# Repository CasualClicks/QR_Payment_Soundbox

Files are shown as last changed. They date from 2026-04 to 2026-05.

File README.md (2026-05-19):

<!-- Generated using AI to save time -->

# 🔊 QR Payment Soundbox

A DIY **QR Payment Soundbox** built using an ESP32 that announces payment confirmations in real-time — matching the performance of commercial UPI soundboxes, but engineered for both **personal (non-merchant) and scalable future use cases**.

---

## 🚀 Overview

This project enables real-time, dynamic **audio announcements for UPI payments** by:

- Subscribing to instant payment payloads via MQTT.
- Parsing numerical amounts and currency fragments asynchronously.
- Outputting clean audio pacing structures through a local hardware decoding matrix.

### Current Support Status:
- 🧑‍💻 **Non-Merchant Mode (Fully Working):** Mobile Phone (SMS Notification App) ➡️ MQTT Broker ➡️ ESP32 WiFi/GPRS Node.
- 🏪 **Merchant Standalone Mode (Hardware Ready / Code Pending):** Circuit architecture accommodates an onboard GSM module for future standalone decoding, currently awaiting firmware implementation.

---

## 📺 Project Demonstration

<div align="center">
  <a href="YOUR_YOUTUBE_VIDEO_URL_HERE">
    Watch the Soundbox Demo
    <br>
    <b>▶️ Click to watch the Soundbox boot up, handle cellular authentication, and process a live transaction payload test</b>
  </a>
</div>

---

## 🧩 Features

- 🔊 **Dynamic Audio Stitching:** Glitch-free compounding playback (e.g., *"Amount received: One Hundred and Fifty Rupees and Fifty Paise"*).
- 📶 **Network Tunnelling:** ESP32 establishes internet access over cellular GPRS (SIM800L) to pull cloud events without local WiFi infrastructure.
- 🎛️ **Compact Amplification Loop:** Minimalist, knobless audio pipeline maximizing space-efficiency.
- 🧠 **Non-Blocking Queue:** Dedicated software state machine managing precise multi-track spacing using dummy timer folders.
- 🧱 **Industrial Form Factor:** Custom-fitted, high-stability 3D printed enclosure.

---

## 🛠️ Hardware Components

| Component | Functional Purpose |
|---|---|
| **ESP32 Core Module** | Central processing unit handling network state machines and audio flow control. |
| **DFPlayer Mini** | Hardware MP3/WAV storage subsystem and local DAC decoder. |
| **PAM8403 Module** | Knobless Mini Class-D Audio Power Amplifier delivering maximum power density. |
| **3W 4Ω Speaker** | Acoustically matched low-impedance audio driver. |
| **SIM800L Core** | GSM/GPRS module providing cellular data connectivity to the MQTT server. |
| **MT3608 DC-DC Boost** | High-transient voltage rail stabilization (Step-up to distinct 4V/5V system domains). |
| **18650 Battery Array** | Core high-discharge portable power cell layout. |
| **Decoupling Capacitors** | Focused $1000\mu F$ low-ESR buffer sitting directly across the cellular power rail. |

---

## 🧠 System Architecture

### 🔹 Non-Merchant Mode (Active Infrastructure)
Payment SMS → Mobile Phone → MQTT Server → ESP32 → Audio Output
1. Payment landing triggers a transactional SMS on a personal smartphone.
2. A background application on the phone reads the broadcast notification and posts a raw string token to the Adafruit IO MQTT broker.
3. The standalone soundbox connects via SIM800L GPRS, extracts the payload value, sanitizes the float bounds, and initiates the local speech thread.

### 🔹 Standalone Merchant Mode (Future Capability)
- SIM800 receives SMS directly  
- ESP32 processes message  
- Fully independent system  
- **Current State:** The wiring matrix accommodates hardware mapping to capture cellular broadcasts natively, but firmware parsing logic is currently placeholder code slated for a future update.
---

## 🔌 Wiring Overview
### 🎛️ Microcontroller Routing Matrix
```cpp
// Hardware Serial 1 Allocation (Cellular Core)
#define ESP_RX_SIM_TX 4  // Connect to SIM800L TX
#define ESP_TX_SIM_RX 5  // Connect to SIM800L RX (Use 1k resistor inline)

// Hardware Serial 2 Allocation (Audio Core)
#define ESP_RX_DF_TX  27 // Connect to DFPlayer Mini TX
#define ESP_TX_DF_RX  25 // Connect to ESP32 TX ---> DFPlayer RX (Use 1k resistor inline)
```
---

## 🔊 Knobless Audio Execution Path
To maximize space and reduce manual physical tuning inside the housing, a knobless PAM8403 module is deployed. Volume adjustments are configured 100% via firmware down to the DFPlayer DAC line (df.volume(15) to 25).

DFPlayer DAC_R / DAC_L -> Routed directly to the PAM8403 Left / Right Input terminals.

DFPlayer GND ➡️ Tied directly to PAM8403 Audio Input Ground.

PAM8403 Output (L+/L- or R+/R-) ➡️ Wired directly to the 3W 4Ω Speaker.

---

## 🔊 Audio Strategy

- Uses **pre-recorded audio clips**
  
SD CARD ROOT/
├── 01/             # Core Numeric Elements [F_NUM]
│   ├── 001.wav     # "One"
│   ├── 020.wav     # "Twenty"
│   └── 030.wav     # "Hundred / Thousand" markers
├── 02/             # Device Status Alerts [F_SYS]
│   ├── 001.wav     # System Booting Sound (S_BOOTING)
│   ├── 002.wav     # Network Registered Sound (S_NETWORK)
│   ├── 003.wav     # Incoming Message Alert Ding (S_DING)
│   └── 004.wav     # Device Online & MQTT Ready (S_READY)
├── 03/             # Sentence Joining Fragments [F_WORDS]
│   ├── 001.wav     # "Paise" (W_PAISE)
│   ├── 002.wav     # "Rupees" (W_RUPEES)
│   ├── 003.wav     # "And" (W_AND)
│   ├── 004.wav     # "Amount" (W_AMOUNT)
│   └── 005.wav     # "Received" (W_RECEIVED)
└── 04/             # Exception Warnings [F_ERR]
    ├── 001.wav     # No Cellular Service Alert (E_NO_SRV)
    ├── 002.wav     # Failed Payment Status (E_NO_PAY)
    └── 003.wav     # General System Hardware Error (E_ERROR)
    
Supports:
- Dynamic composition (number + words)
- OR pre-generated full phrases (recommended)

👉 Recommended format:
- WAV (16-bit, 16kHz, mono)

---

## 🧪 Prototyping & Testing

Before full enclosure integration, individual modules were rigorously unit-tested across power draw cycles.

### 🔬 Evolution Stages
<div align="center">
  Breadboard Circuit Layout
  Assembled Hardware Matrix
  <p><i>Left: Prototype breadboard validation circuit. Right: Main components integrated with power rails inside the final housing chassis.</i></p>
</div>

### ✅ Unit Tests Conducted
- ESP32 ↔ DFPlayer serial command continuity  
- SIM800L registration stabilization under $2\text{A}$ transient load bursts  
- Cellular GPRS session persistence & MQTT heartbeat logic (`state == -1` mitigation)  

---

### ✅ Unit Tests Conducted
- ESP32 ↔ DFPlayer communication  
- ESP32 ↔ SIM800 communication  
- Audio playback stability  
- Power supply reliability  
- MQTT message handling  

### 🔬 Prototype Iterations
- Breadboard setup  
- Perfboard integration  
- Full system assembly  

📸 Images of each stage are included in the repository.

---

## 🧱 Enclosure Design & CAD

- Custom designed multi-piece shell engineered within Fusion 360 to optimize acoustic resonance and component packaging constraints.

<div align="center">
  Fusion 360 Model
  3D Printed Components
  <br>
  Mechanical Assembly Fit Test
  <p><i>Top-Left: 3D modeling and layout parameters. Top-Right: Raw printed shells. Bottom: Structural test alignment before final adhesive lock.</i></p>
</div>

Designed to:
- Securely mount the 18650 cell cluster and MT3608 buck-boost converter safely.
- Feature internal guide tracks for optimal cellular antenna separation from audio traces.
- Support interchangeable front branding faceplates.

---

## ⚡ Power Design

- Battery-powered system  

Using DC-DC boosters for:
- Stable 5V (ESP32, DFPlayer, PAM)
- Stable ~4V (SIM800)

👉 Decoupling capacitors added for stability

---

## 🌐 MQTT Integration

- **Broker Target Host:** `io.adafruit.com` (Port: `1883`)
- **Subscription Feed:** `CasualClicks/feeds/amount`
- **Handshake Tuning:** Buffer depth is explicitly extended to `512` bytes with a robust `120s` keep-alive threshold to smoothly navigate high-latency cellular network environments.

### Expected Metric Payload Object:
```json
{
  "amount": "250.75"
}
```
---

## 📈 Scalability

- Supports multiple devices via MQTT  
- Can be deployed across shops  
- SIM-based version removes dependency on phone  

---

## 🔮 Future Improvements

- App-based dashboard  
- Multi-language support  
- Voice customization  
- Better audio stitching  
- OTA updates  
- Battery optimization  

---

## 🌍 Project Showcase

This project will also be showcased on:  
👉 https://www.officialshivam.in/

---

## 🤝 Contributions

Feel free to:

- Open issues  
- Suggest improvements  
- Fork and build your own version  

---

## 📜 License

MIT License

---

## 🙌 Acknowledgements

Inspired by real-world UPI soundboxes used in retail environments.

---

## 📬 Contact

**Shivam Singhal**

For queries, collaborations, or improvements — feel free to reach out!

---

⭐ If you found this useful, consider starring the repo!

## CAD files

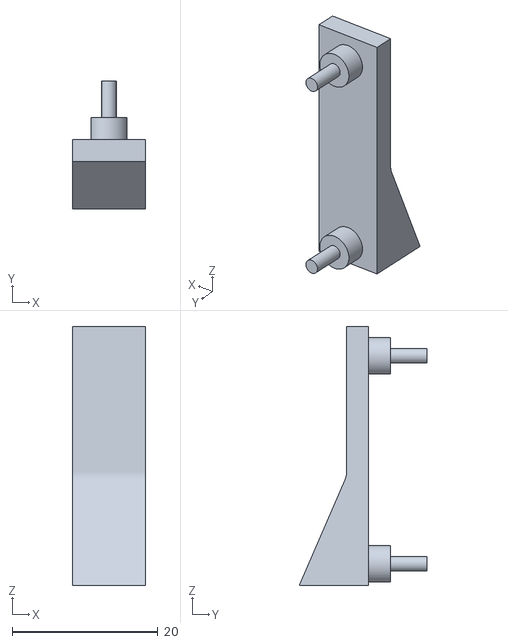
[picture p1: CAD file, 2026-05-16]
Bracket_2_V1.stl
10.0 x 17.5 x 35.5

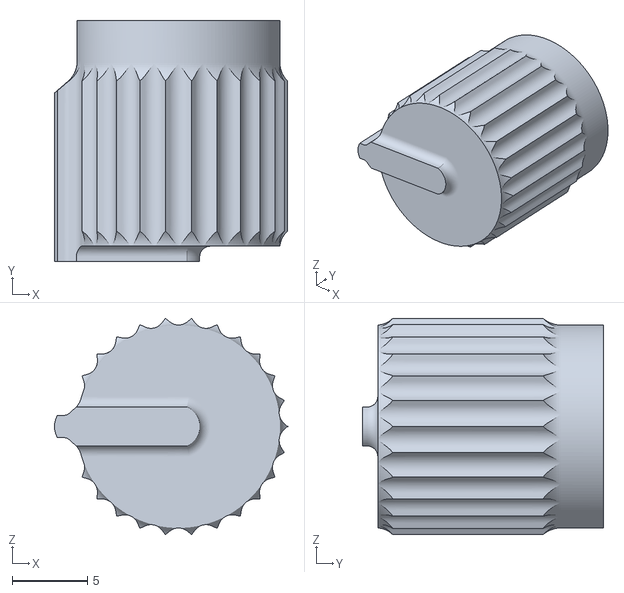
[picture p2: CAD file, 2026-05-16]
VolumeKnobV4.stl
15.5 x 16.0 x 14.4

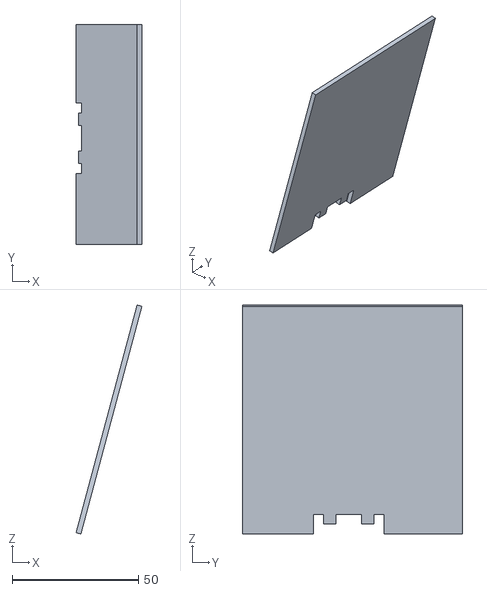
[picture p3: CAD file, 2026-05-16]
Soundbox_QR_Plate_V2.stl
26.1 x 87.0 x 90.7

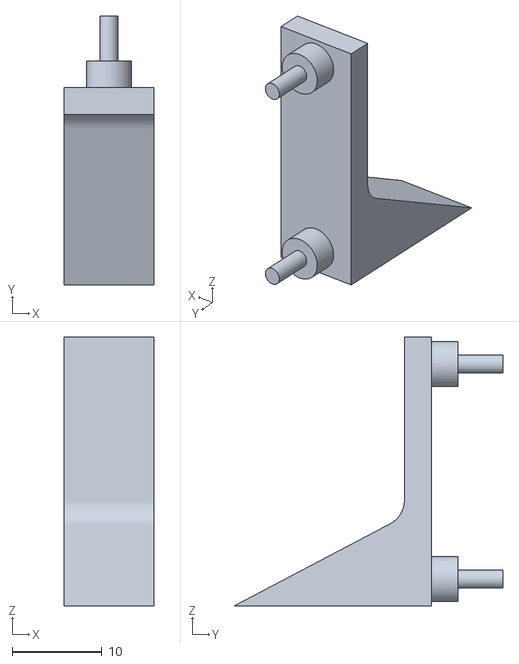
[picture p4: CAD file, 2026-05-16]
Bracket_1_V1.stl
10.0 x 30.0 x 30.0

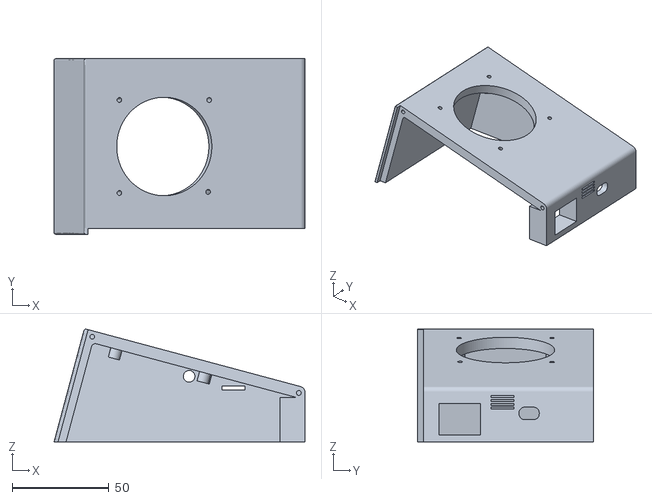
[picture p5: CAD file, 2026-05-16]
soundbox_shell_V1.stl
130.0 x 91.0 x 58.5

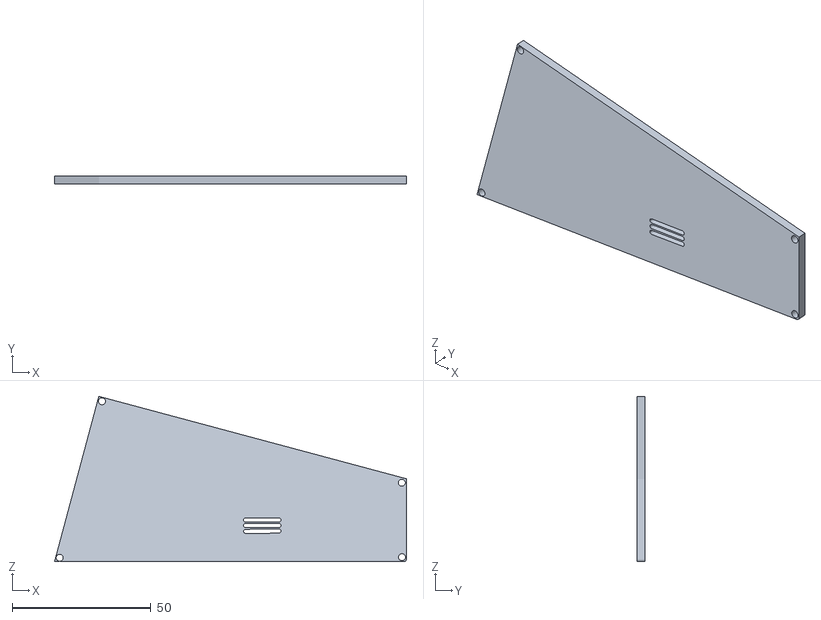
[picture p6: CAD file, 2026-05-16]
Soundbox_Screw_Plate_V1.stl
126.7 x 3.00 x 59.5

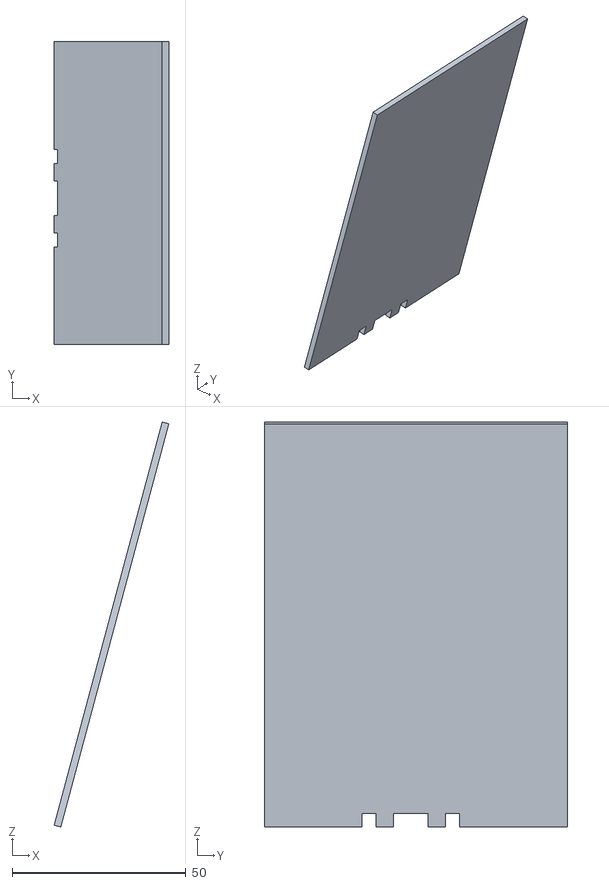
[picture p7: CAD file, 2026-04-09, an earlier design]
Soundbox_QR_Plate_V1.stl
33.0 x 87.0 x 116.4

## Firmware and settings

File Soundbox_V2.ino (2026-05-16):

#include <Arduino.h>
#define TINY_GSM_MODEM_SIM800
#include <TinyGsmClient.h>
#include <PubSubClient.h>
#include <HardwareSerial.h>
#include <DFRobotDFPlayerMini.h>

// ================= CONFIG =================
const char apn[]      = "www";   // VI APN
const char gprsUser[] = "";
const char gprsPass[] = "";

const char* broker    = "io.adafruit.com";
const char* topic     = "OUR_ADAFRUIT_TOPIC";
const char* mqtt_user = "YOUR_ADAFRUIT_USER";
const char* mqtt_pass = "YOUR_ADAFRUIT_KEY";

bool isFirstConnect = true; 
// ================= PINS =================
#define ESP_RX_SIM_TX 4 
#define ESP_TX_SIM_RX 5 
#define ESP_RX_DF_TX  27
#define ESP_TX_DF_RX  25

// ================= AUDIO MAP =================
// Folders
#define F_NUM    1
#define F_SYS    2
#define F_WORDS  3
#define F_ERR    4
#define F_PAUSE  99 // MAGIC FOLDER: Used to create silent gaps

// System Sounds (Folder 02)
#define S_BOOTING  1
#define S_NETWORK  2
#define S_DING     3
#define S_READY    4

// Word Sounds (Folder 03)
#define W_PAISE    1
#define W_RUPEES   2
#define W_AND      3
#define W_AMOUNT   4
#define W_RECEIVED 5

// Error Sounds (Folder 04)
#define E_NO_SRV   1
#define E_NO_PAY   2
#define E_ERROR    3

// ================= OBJECTS =================
HardwareSerial SerialAT(1);
HardwareSerial mp3Serial(2);
TinyGsm modem(SerialAT);
TinyGsmClient client(modem);
PubSubClient mqtt(client);
DFRobotDFPlayerMini df;

// ================= AUDIO QUEUE =================
int queue[40]; 
int queueSize = 0, currentIndex = 0;

bool isPlaying = false;
unsigned long lastCommandTime = 0;

// Pause Variables
bool isPausing = false;
unsigned long pauseEndTime = 0;

void addToQueue(int folder, int file) {
  if (queueSize < 40) queue[queueSize++] = (folder * 10000) + file;
}

void playNext() {
  if (currentIndex >= queueSize) {
    isPlaying = false;
    isPausing = false;
    queueSize = 0;
    currentIndex = 0;
    Serial.println("[INFO] Audio queue finished");
    return;
  }

  int val = queue[currentIndex++];
  int folder = val / 10000;
  int file = val % 10000;

  if (folder == F_PAUSE) {
    Serial.printf("[INFO] Silent Pause for %d ms...\n", file);
    pauseEndTime = millis() + file;
    isPausing = true;
    isPlaying = false;
  } 
  else {
    Serial.printf("[INFO] Playing -> Folder: %02d | File: %03d\n", folder, file);
    df.playFolder(folder, file);
    lastCommandTime = millis();
    isPlaying = true;
    isPausing = false;
  }
}

void queueNumber(long num) {
  if (num == 0) return;

  if (num <= 20) {
    addToQueue(F_NUM, num);
  } 
  else if (num < 100) {
    addToQueue(F_NUM, (num / 10) + 18); 
    if (num % 10) queueNumber(num % 10);
  } 
  else if (num < 1000) {
    queueNumber(num / 100);
    addToQueue(F_NUM, 28); 
    if (num % 100) queueNumber(num % 100);
  }
  else if (num < 100000) {
    queueNumber(num / 1000);
    addToQueue(F_NUM, 29); 
    if (num % 1000) queueNumber(num % 1000);
  }
  else {
    queueNumber(num / 100000);
    addToQueue(F_NUM, 30); 
    if (num % 100000) queueNumber(num % 100000);
  }
}

// ==== UPGRADED PARSER FOR PAISE ====
void speakAmount(String amount) {
  amount.trim();
  if (amount.length() == 0) return;

  long rupeesVal = 0;
  long paiseVal = 0;

  // Check if there is a decimal point
  int dotIndex = amount.indexOf('.');
  
  if (dotIndex != -1) {
    // Extract the Rupees part before the dot
    rupeesVal = amount.substring(0, dotIndex).toInt();
    
    // Extract the Paise part after the dot
    String pStr = amount.substring(dotIndex + 1);
    
    // Safety check: if they send "150.5" it means 50 paise.
    if (pStr.length() == 1) {
      pStr += "0"; 
    } else if (pStr.length() > 2) {
      pStr = pStr.substring(0, 2); // Ignore anything past 2 decimals
    }
    paiseVal = pStr.toInt();
  } else {
    // No decimal found, it's just pure rupees
    rupeesVal = amount.toInt();
  }

  // If amount is literally 0.00, ignore it
  if (rupeesVal <= 0 && paiseVal <= 0) return;

  Serial.println("\n[EVENT] Processing Payment: ₹" + amount);
  Serial.printf("[INFO] Parsed -> Rupees: %ld | Paise: %ld\n", rupeesVal, paiseVal);

  queueSize = 0;
  currentIndex = 0;

  // ==== THE PACING SEQUENCE ====
  addToQueue(F_SYS, S_DING);       // 1. Play the Ding
  addToQueue(F_PAUSE, 500);        // 2. Pause
  
  addToQueue(F_WORDS, W_AMOUNT);   // 3. "Amount"
  addToQueue(F_WORDS, W_RECEIVED); // 4. "Received"
  
  // 5. Speak Rupees (if any)
  if (rupeesVal > 0) {
    queueNumber(rupeesVal);        
    addToQueue(F_WORDS, W_RUPEES); // "Rupees"
  }

  // 6. Speak Paise (if any)
  if (paiseVal > 0) {
    // If we already said rupees, insert the word "And"
    if (rupeesVal > 0) {
      addToQueue(F_WORDS, W_AND);  
    }
    queueNumber(paiseVal);         // Speak the decimal numbers
    addToQueue(F_WORDS, W_PAISE);  // "Paise"
  }

  playNext(); // Kick off the queue
}

// ================= MQTT =================
void callback(char* topic, byte* payload, unsigned int len) {
  char msg[len + 1];
  memcpy(msg, payload, len);
  msg[len] = '\0';

  Serial.println("[INFO] MQTT Message Received: " + String(msg));
  speakAmount(String(msg));
}

void connectMQTT() {
  String clientId = "SoundBox-" + String(micros());

  // Add a local counter to prevent the "No Service" sound from looping
  int retryCount = 0;

  while (!mqtt.connected()) {
    modem.sendAT("+CNETLIGHT=1"); 
    modem.waitResponse();

    Serial.println("[INFO] Connecting to MQTT Broker...");

    if (mqtt.connect(clientId.c_str(), mqtt_user, mqtt_pass)) {
      Serial.println("[INFO] MQTT Connected Successfully!");
      mqtt.subscribe(topic);
      
      modem.sendAT("+CNETLIGHT=0"); 
      modem.waitResponse();
      
      // Only play "Ready" on the very first successful boot
      if (isFirstConnect) {
        df.playFolder(F_SYS, S_READY); 
        isFirstConnect = false; 
      }
      else{
      Serial.println("[INFO] MQTT Reconnected");      
      }
    } 
    else {
      Serial.print("[WARN] MQTT Failed, rc=");
      Serial.println(mqtt.state());
      
      // ONLY play "No Service" on the first failure. 
      // This prevents the box from shouting every 5 seconds.
      if (retryCount == 0 && isFirstConnect) {
         df.playFolder(F_ERR, E_NO_SRV); 
      }
      
      retryCount++;
      delay(5000); // Wait 5 seconds before trying again
    }
  }
}

// ================= SETUP =================
void setup() {
  Serial.begin(115200);
  delay(3000);

  Serial.println("\n=================================");
  Serial.println("    SOUNDBOX BOOT SEQUENCE       ");
  Serial.println("=================================");
  randomSeed(micros());

  // --- DFPlayer Init ---
  Serial.println("[INIT] Starting DFPlayer...");
  mp3Serial.begin(9600, SERIAL_8N1, ESP_RX_DF_TX, ESP_TX_DF_RX);
  if (!df.begin(mp3Serial)) {
    Serial.println("[ERROR] DFPlayer missing or wiring faulty!");
  } else {
    Serial.println("[INFO] DFPlayer Ready. Volume set to 25.");
    df.volume(15);
    df.playFolder(F_SYS, S_BOOTING); 
  }

  // --- SIM800 Init ---
  Serial.println("[INIT] Starting SIM800L...");
  SerialAT.begin(9600, SERIAL_8N1, ESP_RX_SIM_TX, ESP_TX_SIM_RX);

  // FORCE NETLIGHT ON IMMEDIATELY
  // We send a raw AT command because 'modem.init()' hasn't passed yet
  Serial.println("[DEBUG] Forcing Netlight ON for troubleshooting...");
  SerialAT.println("AT+CNETLIGHT=0"); 
  delay(100);
  
  Serial.println("[INFO] Syncing Modem...");
  if (!modem.init()) {
    Serial.println("[ERROR] Modem init failed! Check power/wiring.");
    df.playFolder(F_ERR, E_ERROR); 
    while (true);
  }
  
  modem.sendAT("+CNETLIGHT=0"); 
  modem.waitResponse(); 
  Serial.println("[INFO] Netlight disabled.");
  
  Serial.println("[INFO] Waiting for cellular network...");
  if (!modem.waitForNetwork(60000L)) {
    Serial.println("[ERROR] No Network Signal.");
    df.playFolder(F_ERR, E_ERROR);
    while (true); 
  }

  Serial.println("[INFO] Cellular Network Found!");

  Serial.println("[INFO] Establishing GPRS (Internet)...");
  if (!modem.gprsConnect(apn, gprsUser, gprsPass)) {
    Serial.println("[ERROR] GPRS Connection Failed.");
    df.playFolder(F_ERR, E_NO_SRV);
    while (true); 
  }

  Serial.println("[INFO] Internet Connection Established!");
  df.playFolder(F_SYS, S_NETWORK); 

  mqtt.setServer(broker, 1883);
  mqtt.setCallback(callback);

  mqtt.setBufferSize(512);   // Gives more room for cellular data packets
  mqtt.setKeepAlive(120);    // Tells Adafruit to wait 2 minutes before disconnecting


  Serial.println("[INFO] Setup Complete. Entering Loop.");
}

// ================= LOOP =================
void loop() {
  if (!mqtt.connected()) {
    Serial.print("[DEBUG] Connection lost. Internal State: ");
    Serial.println(mqtt.state()); // This will tell us WHY it dropped
    connectMQTT();
  }

  mqtt.loop();

  if (isPausing && (millis() >= pauseEndTime)) {
    playNext();
  }

  if (df.available()) {
    uint8_t type = df.readType();
    
    if (isPlaying && type == DFPlayerPlayFinished) {
      if (millis() - lastCommandTime > 150) {
        playNext();
      }
    }
  }
}

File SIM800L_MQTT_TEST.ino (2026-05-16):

#include <Arduino.h>
#define TINY_GSM_MODEM_SIM800
#include <TinyGsmClient.h>
#include <PubSubClient.h>
#include <HardwareSerial.h>
#include <DFRobotDFPlayerMini.h>

// ================= CONFIGURATION =================
const char apn[]      = "www"; // VI APN (Alternative: "smartnet")
const char gprsUser[] = "";
const char gprsPass[] = "";

const char* broker    = "io.adafruit.com";
const char* topic     = "OUR_ADAFRUIT_TOPIC";
const char* mqtt_user = "YOUR_ADAFRUIT_USER";
const char* mqtt_pass = "YOUR_ADAFRUIT_KEY";

// ================= PINS =================
#define SIM_TX 17
#define SIM_RX 16
#define DF_TX  25
#define DF_RX  26
#define LED_RED 33   // RGB Red
#define LED_GRN 32   // RGB Green
#define LED_BLU 35   // RGB Blue

// ================= OBJECTS =================
HardwareSerial SerialAT(1);
HardwareSerial mp3Serial(2);
TinyGsm modem(SerialAT);
TinyGsmClient client(modem);
PubSubClient mqtt(client);
DFRobotDFPlayerMini df;

// ================= AUDIO QUEUE =================
int queue[30];
int queueSize = 0, currentIndex = 0;
bool isPlaying = false;
unsigned long lastCommandTime = 0;

void setLED(int r, int g, int b) {
  analogWrite(LED_RED, r);
  analogWrite(LED_GRN, g);
  analogWrite(LED_BLU, b);
}

void addToQueue(int folder, int file) {
  if (queueSize < 30) queue[queueSize++] = (folder * 1000) + file;
}

void playNext() {
  if (currentIndex >= queueSize) {
    isPlaying = false;
    queueSize = 0; currentIndex = 0;
    return;
  }
  int combined = queue[currentIndex++];
  df.playFolder(combined / 1000, combined % 1000);
  lastCommandTime = millis();
  isPlaying = true;
}

void queueNumber(int num) {
  if (num == 0) return;
  if (num <= 20) { addToQueue(1, num); } 
  else if (num < 100) {
    addToQueue(1, (num / 10) + 18); 
    if (num % 10) queueNumber(num % 10);
  } 
  else if (num < 1000) {
    addToQueue(1, num / 100); addToQueue(1, 28);
    if (num % 100) queueNumber(num % 100);
  }
  else if (num < 100000) {
    queueNumber(num / 1000); addToQueue(1, 29);
    if (num % 1000) queueNumber(num % 1000);
  }
}

void speakAmount(String amount) {
  int val = amount.toInt();
  if (val <= 0) return;
  queueSize = 0; currentIndex = 0;
  setLED(0, 255, 255); // Cyan for processing
  addToQueue(3, 4); addToQueue(3, 5);
  queueNumber(val);
  addToQueue(3, 2);
  playNext();
}

// ================= MQTT CALLBACK =================
void callback(char* topic, byte* payload, unsigned int len) {
  char message[len + 1];
  memcpy(message, payload, len);
  message[len] = '\0';
  speakAmount(String(message));
}

void connectMQTT() {
  while (!mqtt.connected()) {
    setLED(0, 0, 255); // Blue: Attempting MQTT
    String clientId = "ESP32-Box-" + String(random(0, 999));
    if (mqtt.connect(clientId.c_str(), mqtt_user, mqtt_pass)) {
      mqtt.subscribe(topic);
      setLED(0, 255, 0); // Green: Ready
    } else {
      setLED(255, 0, 0); // Red: Failed
      delay(5000);
    }
  }
}

void setup() {
  Serial.begin(115200);
  delay(1000);
  Serial.println("System Booting Up");
  pinMode(LED_RED, OUTPUT); pinMode(LED_GRN, OUTPUT); pinMode(LED_BLU, OUTPUT);
  
  setLED(255, 255, 0); // Yellow: Booting

  mp3Serial.begin(9600, SERIAL_8N1, DF_RX, DF_TX);
  if (!df.begin(mp3Serial)) while(true);
  df.volume(28);

  // SIM800L Setup
  SerialAT.begin(115200, SERIAL_8N1, SIM_RX, SIM_TX);
  delay(3000);
  Serial.println("Initializing modem...");
  modem.restart();

modem.sendAT("+CNETLIGHT=0"); 
Serial.println("Netlight disabled to save power.");

  Serial.println("Waiting for network...");
  if (!modem.waitForNetwork()) {
    setLED(255, 0, 0);
    while(true);
  }

  Serial.println("Connecting GPRS...");
  if (!modem.gprsConnect(apn, gprsUser, gprsPass)) {
    setLED(255, 0, 0);
    while(true);
  }

  mqtt.setServer(broker, 1883);
  mqtt.setCallback(callback);
}

void loop() {
  if (!mqtt.connected()) connectMQTT();
  mqtt.loop();

  if (isPlaying && (millis() - lastCommandTime > 600)) { 
    if (df.available() && df.readType() == DFPlayerPlayFinished) {
      playNext();
      if (!isPlaying) setLED(0, 255, 0); // Back to Green after speaking
    }
  }
}

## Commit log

2026-04-09 Enhance README with comprehensive project details
    Expanded the README to include detailed project overview, features, system architecture, wiring overview, audio strategy, prototyping and testing information, enclosure design, power design, MQTT int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
2026-04-09 Models and test Files
    [Soundbox_QR_Holder_Bracket.stl, Soundbox_QR_Plate.stl, Soundbox_Screw_PLate_V2.stl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]
2026-05-16 new changes
    [Bracket_1_V1.stl, Bracket_2_V1.stl, Soundbox_QR_Holder_Bracket.stl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]
2026-05-16 Revise README for project demo and enclosure design
    Updated project demonstration section and refined enclosure design details.
